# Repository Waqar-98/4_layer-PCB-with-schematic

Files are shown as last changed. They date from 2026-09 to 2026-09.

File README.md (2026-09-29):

4-Layer ESP32 Sensor Board

A battery-powered, USB-C rechargeable ESP32-C3 sensor node integrating environmental (temperature/humidity/pressure), ambient light, and sound sensing, with onboard USB-to-UART programming, microSD data logging, and an I2C display header. This repository is a **revision** of the original 2-layer design, re-laid-out as a **4-layer PCB** (dedicated inner power/ground planes) for improved signal integrity and routing.

| | |
|---|---|
| **MCU/Module** | ESP32-C3-WROOM-02-H4 (U3) |
| **USB-UART Bridge** | Silicon Labs CP2102N-A02-GQFN20 (U4) |
| **Layers** | 4 (F.Cu, In1.Cu, In2.Cu, B.Cu) |
| **Interfaces** | USB-C (USB 2.0), I2C, microSD (SPI), SPI NOR flash, GPIO breakout |
| **Power** | USB-C 5 V input, single-cell LiPo (JST 2 mm), onboard charge management |
| **Revision** | 2 (4-layer revision) |
| **Status** | In development |

---

## Table of Contents

1. [Overview](#1-overview)
2. [Features](#2-features)
3. [Hardware Description](#3-hardware-description)
4. [Schematics](#4-schematics)
5. [PCB Layout](#5-pcb-layout)
6. [ESP32-C3 Pin Mapping](#6-esp32-c3-pin-mapping)
7. [Connector Pinout](#7-connector-pinout)
8. [Power Supply](#8-power-supply)
9. [Getting Started](#9-getting-started)
10. [Repository Structure](#10-repository-structure)
11. [Bill of Materials](#11-bill-of-materials)
12. [Revision History](#12-revision-history)

---

## 1. Overview

This board is a compact, self-contained sensor node built around the ESP32-C3-WROOM-02-H4 module. It integrates a BME280 environmental sensor, a TEMT6000 ambient light sensor, and an electret microphone with an adjustable-gain amplifier, alongside a microSD card slot and an external SPI NOR flash for local data logging. Power comes from either USB-C or a single-cell LiPo battery, with onboard charge management and power-path switching so the board can run and charge simultaneously. An onboard CP2102N provides USB-to-UART programming and an automatic reset/bootloader-entry circuit, so no external programmer is required.

This revision re-lays out the board on **4 copper layers** instead of 2, adding dedicated inner power (3.3 V) and ground planes. This improves return-path continuity and reduces plane impedance/noise for the analog sensor front-ends (microphone amplifier, light sensor) and the SPI/I2C digital buses, compared with the original 2-layer version.

## 2. Features

- **ESP32-C3-WROOM-02-H4** (U3) — RISC-V single-core Wi-Fi/BLE module
- **BME280** (U7) environmental sensor — temperature, humidity, and pressure over I2C, address-select pad for 0x76/0x77
- **TEMT6000X01** (Q1) ambient light phototransistor with RC-filtered analog output
- **Electret microphone** (MK1, CMC-5042PF-AC) with a **MAX4466EXK+T** (U8) op-amp amplifier and a trimmer potentiometer (R17, 100 kΩ) for adjustable gain
- **microSD card slot** (J3, GSD090012SEU) on a shared SPI bus
- **32 Mbit external SPI NOR flash** (U6, W25Q32JVSSIQ) sharing the same SPI bus with an independent chip select, for onboard data logging separate from the module's program flash
- **Onboard USB-to-UART bridge** (U4, CP2102N-A02-GQFN20) with USB ESD protection (U5, USBLC6-2SC6) — no external FTDI/CH340 adapter needed to program the board
- **Automatic reset/bootloader-entry circuit** using two BC817 transistors (Q2, Q3) driven from DTR/RTS, following the standard ESP32 auto-program sequence
- **USB-C power input** (J1) with 5.1 kΩ CC pull-downs for default 5 V/USB 2.0 negotiation
- **LiPo charge management** via a **MCP73871** charger IC (U1) with power-path management, tri-color charge-status LEDs (charging/charged/power-good), and battery connector (J2, JST 2 mm)
- **LM1117MPX-3.3** LDO (U2) regulates the system 3.3 V rail
- Manual **BOOT** and **RESET** buttons (SW1, SW2) in addition to the automatic DTR/RTS circuit
- I2C header (J4) for an external OLED display
- 5-pin breakout header (J6) exposing 3.3 V, GND, and three spare GPIOs (GPIO8, GPIO18, GPIO19)
- Five test points (TP1–TP5) on the shared SPI bus (MOSI, MISO, SCLK, CS_SD, CS) for debugging
- **4-layer stack-up** with dedicated inner 3.3 V and GND planes (this revision)

## 3. Hardware Description

**Power input and charging.** USB-C VBUS (J1) passes through a resettable fuse (F1) to the `+5V_USB` rail. This rail feeds a MCP73871 LiPo charger IC (U1) configured with power-path management: it charges a single-cell LiPo connected at J2 while simultaneously supplying the system load from its `OUT` pin, so the board can operate while charging. Three status outputs (`STAT1`, `STAT2`, `PG`) drive a red/green/blue LED trio (D1–D3) through 470 Ω resistors, giving a visual charge/power-good indication. `OUT` feeds through a ferrite bead (FB1) into an LM1117MPX-3.3 LDO (U2), which produces the board's 3.3 V rail used by every other block.

**MCU and USB programming.** The ESP32-C3-WROOM-02-H4 (U3) is the central module. A CP2102N-A02-GQFN20 USB-to-UART bridge (U4), protected by a USBLC6-2SC6 ESD array (U5) on the USB data lines, connects the module's TX/RX to the host PC and exposes green/red (D5/D6) activity LEDs on its GPIO.2/GPIO.3 lines. DTR and RTS from the CP2102N drive two BC817 transistors (Q2, Q3) that implement the standard auto-reset/auto-bootloader circuit on the `EN` and `BOOT` (GPIO9) lines, so the board can be flashed without manually holding a button. Manual BOOT (SW1) and RESET (SW2) buttons are also provided, each with an RC debounce network.

Notably, because the ESP32-C3's boot-mode strapping pin is GPIO9 (unlike the original ESP32, which straps on GPIO0), this design routes GPIO9 to the `BOOT` net for auto-programming and frees GPIO0 for use as an analog input for the microphone signal (`MIC_OUT`).

**Storage.** A microSD socket (J3, GSD090012SEU) and a 32 Mbit SPI NOR flash (U6, W25Q32JVSSIQ) share one SPI bus (`MOSI_DI`, `MISO_DO`, `SCLK`) with independent chip-select lines (`CS_SD`, `CS`). Series resistors (R15, R20, R22 — annotated on the schematic as ~50 Ω) sit on the shared bus lines to damp ringing at high SPI clock rates. Five test points (TP1–TP5) break out the same bus for probing.

**Sensors.** A BME280 (U7) provides temperature, humidity, and pressure over I2C, with SDA/SCL pull-ups (R24, R25) and a pad to select the I2C address by tying `SDO` to GND (0x76) or `VDDIO` (0x77) — this board ties it to GND. A TEMT6000X01 phototransistor (Q1) with a 10 kΩ pull-down (R23) and RC filtering forms a simple ambient-light sensor read as an analog voltage. An electret microphone (MK1) is biased and AC-coupled into a MAX4466EXK+T op-amp (U8) configured as a non-inverting amplifier; a 22 kΩ resistor plus a 100 kΩ trimmer potentiometer (R31, R17) in the feedback path set the gain, with a 100 pF capacitor (C20) rolling off high-frequency noise.

**User interface.** A 4-pin I2C header (J4, B4B-XH-AM) breaks out 3.3 V/SDA/SCL/GND for an external OLED display. A 5-pin header (J6) exposes 3.3 V, GND, and the three GPIOs (GPIO8/18/19) not otherwise used by the design.

**Stack-up (this revision).** The board was re-laid-out from 2 to 4 copper layers: `F.Cu` (top signal), `In1.Cu` (inner plane), `In2.Cu` (inner plane), `B.Cu` (bottom signal). The inner layers are used as continuous 3.3 V and GND planes, giving the top/bottom signal layers a solid adjacent reference plane and shortening high-frequency return paths for the SPI bus and analog front-ends.

## 4. Schematics

**Power and battery management** (root sheet — USB-C input, LiPo charger, LDO regulator, power-indicator LED, battery connector)

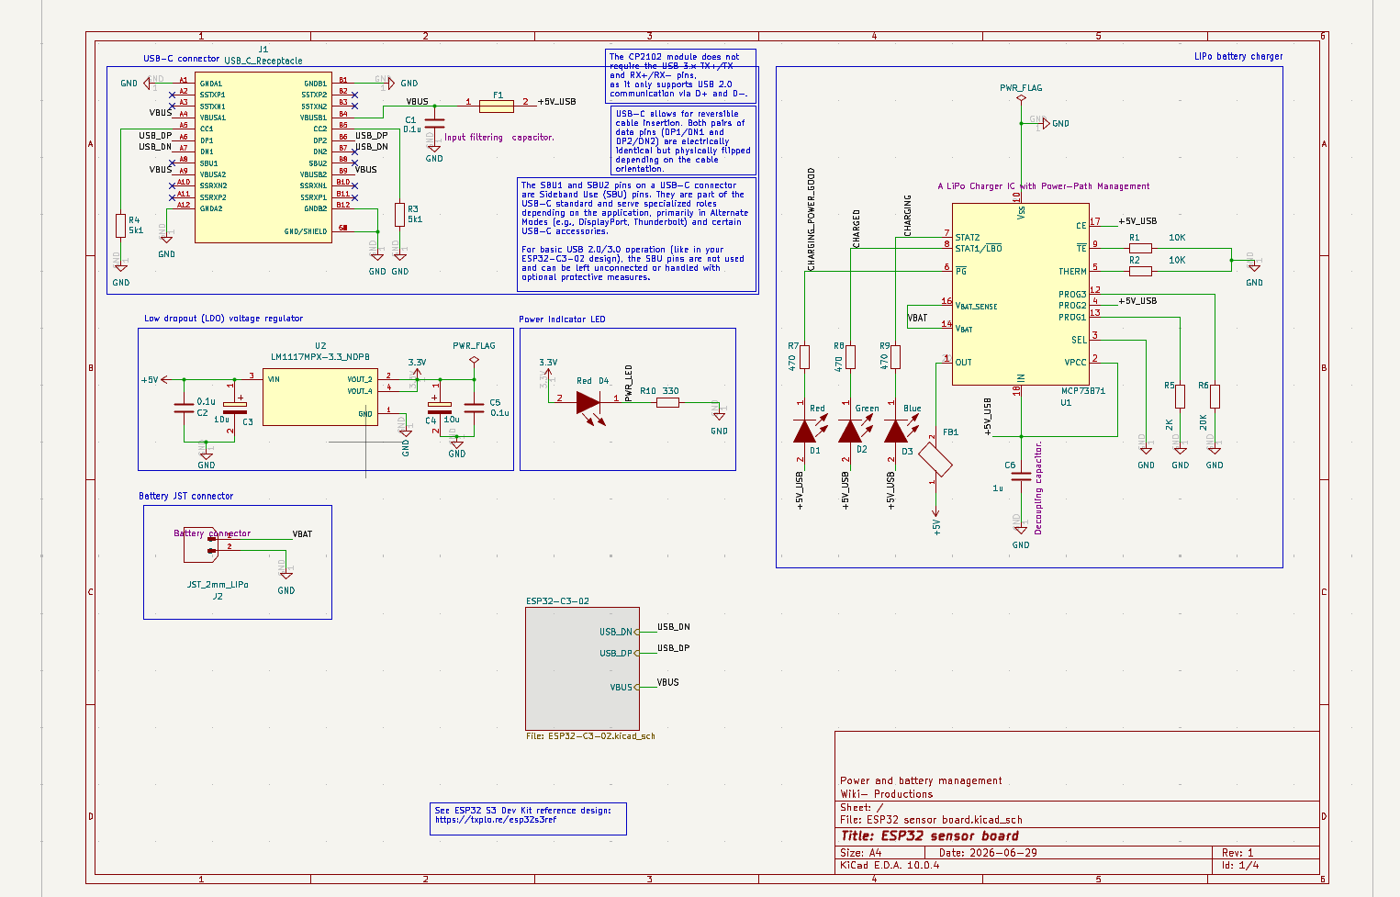
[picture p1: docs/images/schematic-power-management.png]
Power and battery management schematic


**ESP32-C3-02 and USB-to-UART converter** (MCU, CP2102N USB bridge, SPI flash, microSD module, test points)

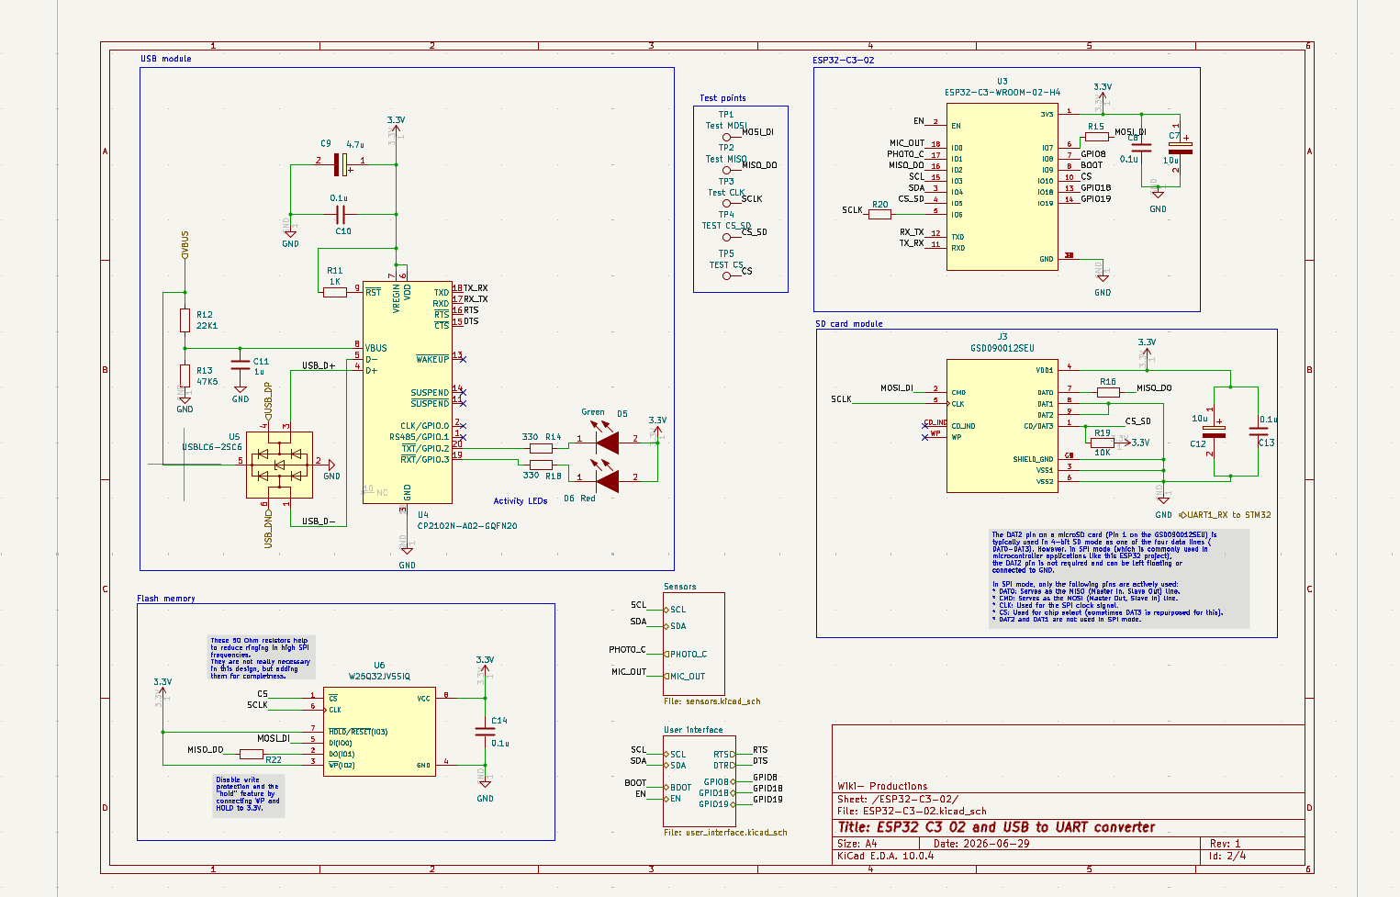
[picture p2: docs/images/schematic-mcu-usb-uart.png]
ESP32-C3-02 and USB-to-UART schematic


**Sensors** (BME280, TEMT6000 light sensor, electret microphone and amplifier)

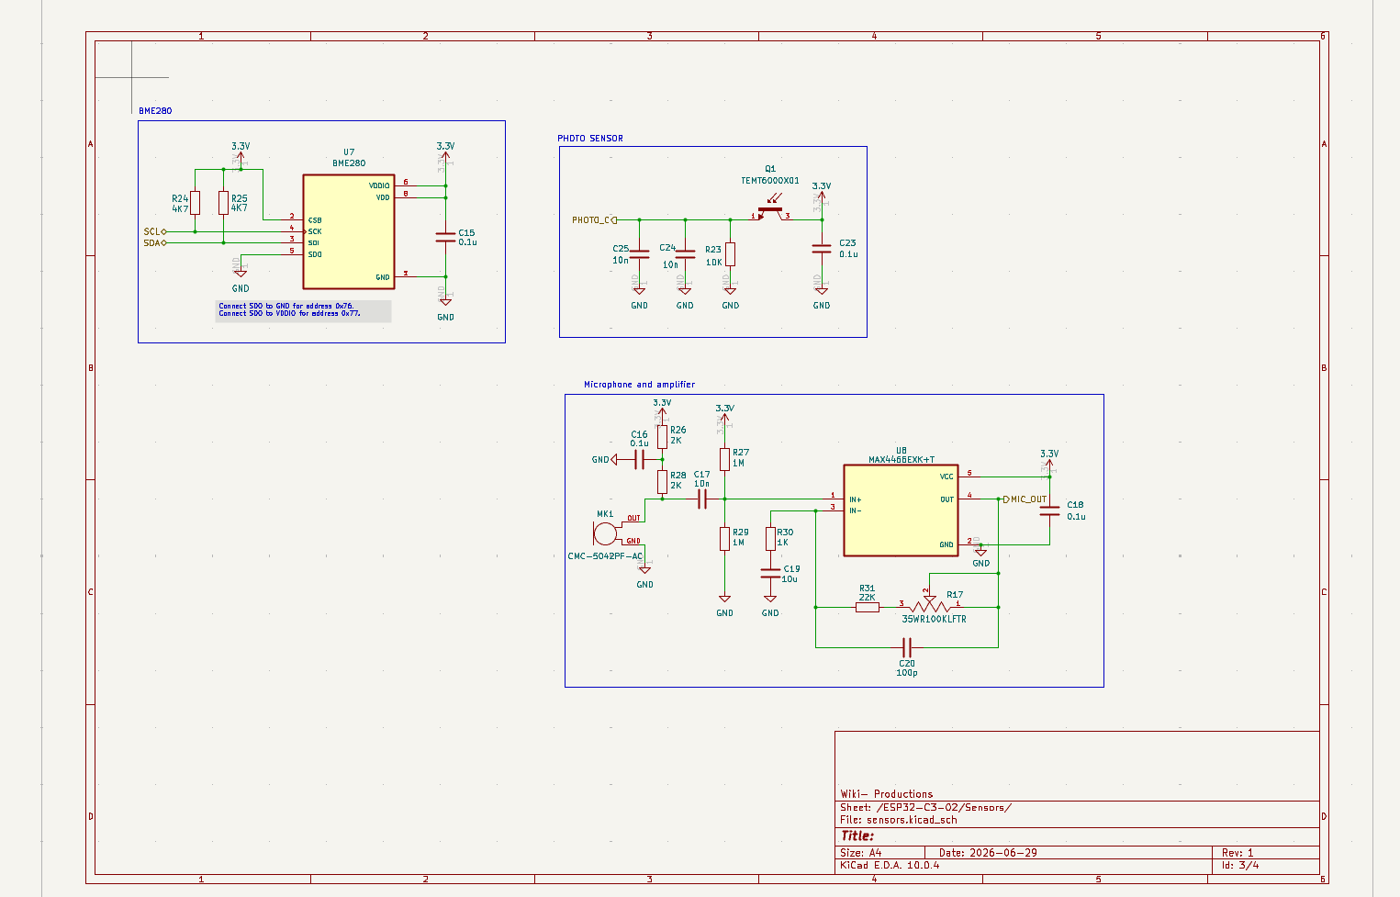
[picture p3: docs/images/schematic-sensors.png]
Sensors schematic


**User interface** (OLED I2C header, GPIO breakout header, reset/boot buttons, auto-program circuit)

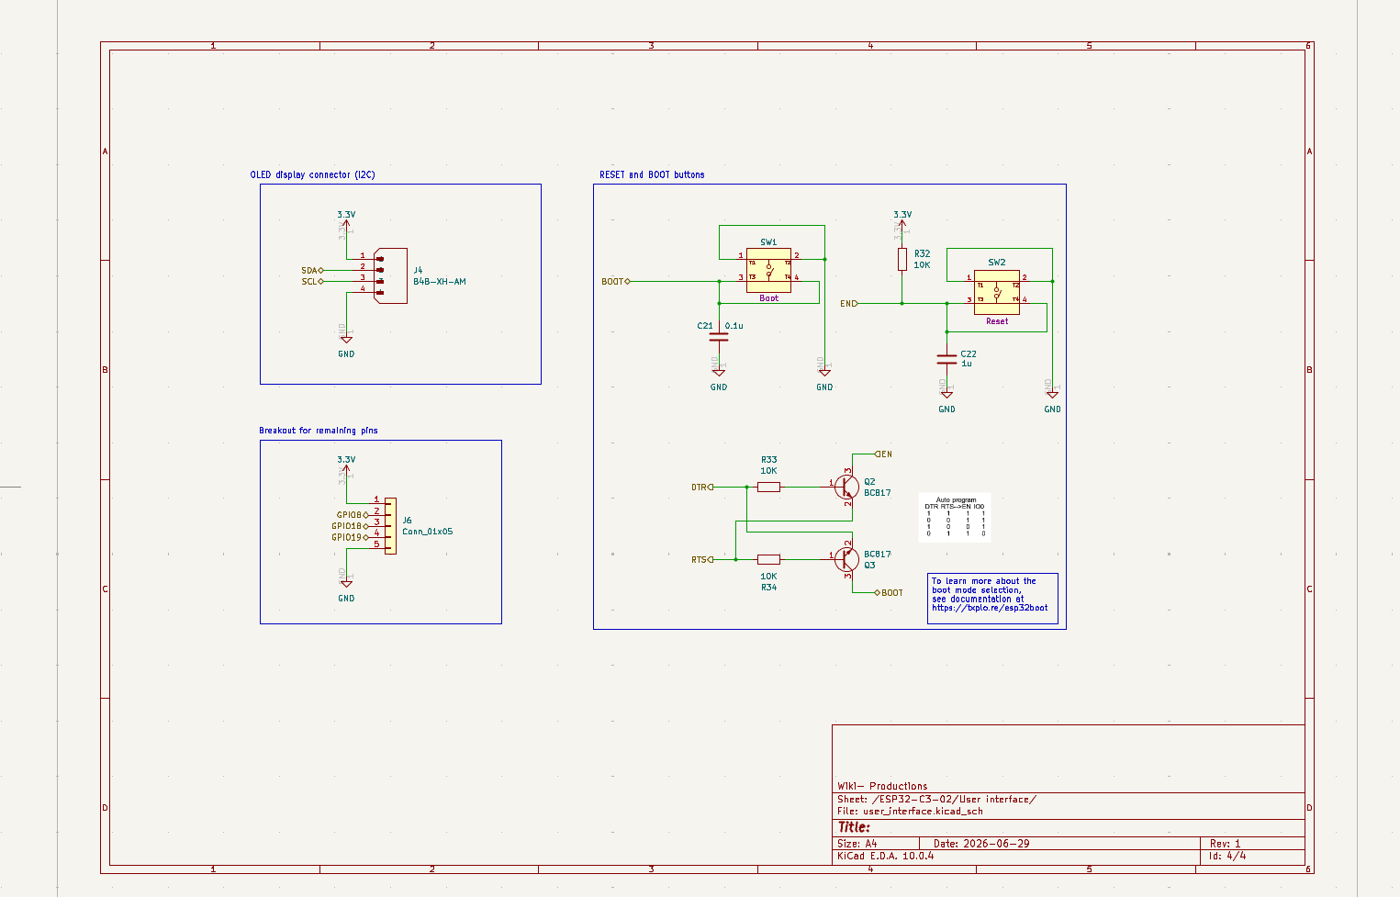
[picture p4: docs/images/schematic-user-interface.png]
User interface schematic


## 5. PCB Layout

Four-layer board (top copper in red, bottom copper in blue, inner planes not separately colored in the 2D view) with a stepped outline: the sensor cluster (microphone, light sensor, BME280) sits along the top edge, charging/regulation/USB circuitry occupies the left and lower-left, and the ESP32 module, SPI flash, and microSD slot are grouped on the right where the board extends further along the top edge. A hatched keep-out zone sits directly next to the ESP32-C3-WROOM-02 footprint, consistent with the module's onboard PCB antenna clearance requirement. A second hatched/unpopulated zone, silkscreened `proto#2`, appears to be a reserved prototyping area. The layout includes multiple mounting holes and five silkscreened test points (TP1–TP5) on the shared SPI bus — exact hole counts, diameters, and keep-out dimensions should be confirmed against the PCB source file.

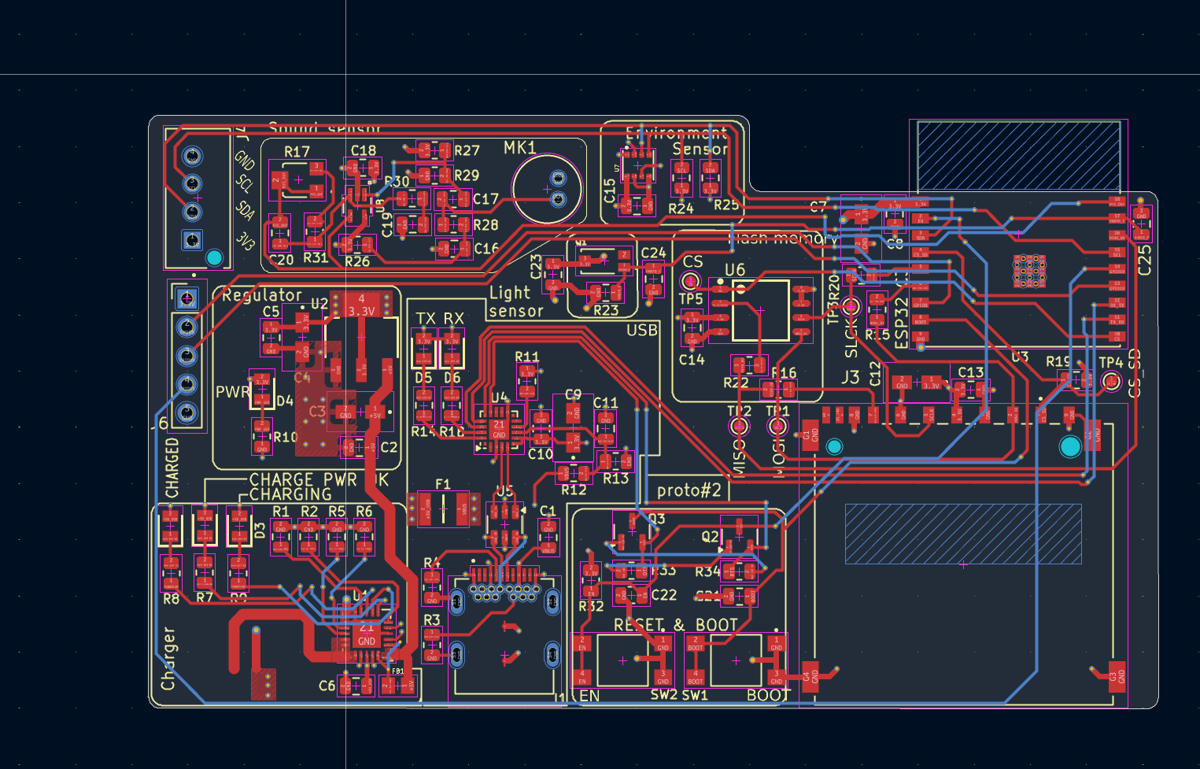
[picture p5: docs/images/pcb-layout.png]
PCB layout


**3D Render**

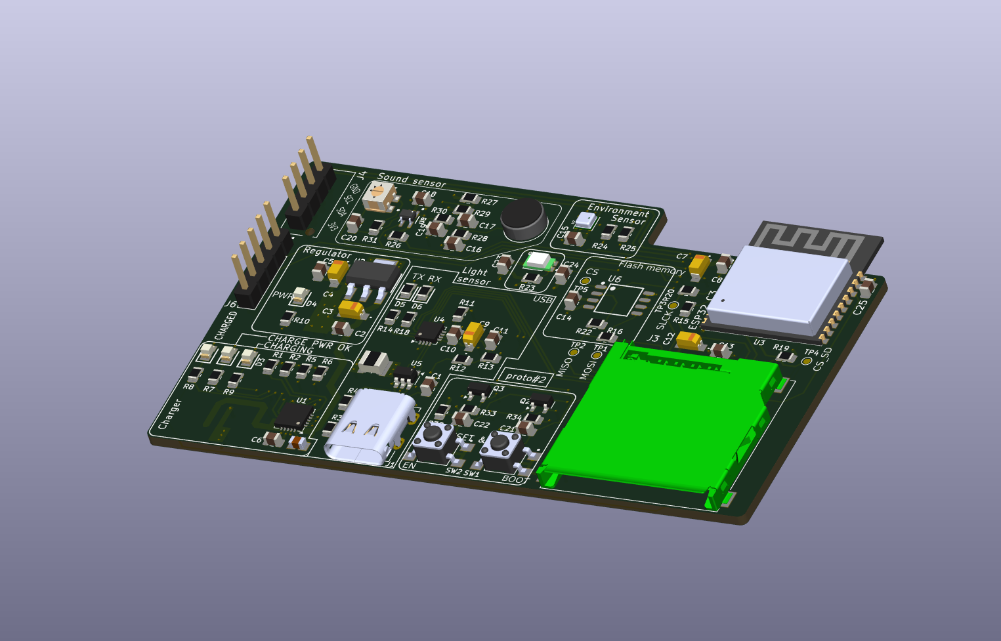
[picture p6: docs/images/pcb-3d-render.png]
PCB 3D render


## 6. ESP32-C3 Pin Mapping

Pin assignments below are read directly from the ESP32-C3-WROOM-02-H4 (U3) schematic symbol. Verify against the source design files prior to firmware development.

| Module Pin | GPIO | Net / Function |
|---|---|---|
| 1 | 3V3 | 3.3 V supply |
| 2 | EN | Chip enable / reset (auto-program + RESET button) |
| 18 | IO0 | `MIC_OUT` — microphone amplifier analog output |
| 17 | IO1 | `PHOTO_C` — light sensor analog output |
| 16 | IO2 | `MISO_DO` — shared SPI bus (flash + microSD) |
| 15 | IO3 | `SCL` — I2C clock (BME280, OLED header) |
| 3 | IO4 | `SDA` — I2C data (BME280, OLED header) |
| 4 | IO5 | `CS_SD` — microSD chip select |
| 5 | IO6 | `SCLK` — shared SPI bus clock (via R20) |
| 6 | IO7 | `MOSI_DI` — shared SPI bus data out (via R15) |
| 7 | IO8 | `GPIO8` — broken out to J6 |
| 8 | IO9 | `BOOT` — boot-mode strap / auto-program (via Q3) |
| 10 | IO10 | `CS` — SPI flash chip select |
| 13 | IO18 | `GPIO18` — broken out to J6 |
| 14 | IO19 | `GPIO19` — broken out to J6 |
| 12 | TXD | `RX_TX` — to CP2102N |
| 11 | RXD | `TX_RX` — from CP2102N |
| — | GND | Ground |

## 7. Connector Pinout

Pin assignments below are derived from the schematics. Verify against the source design files and PCB silkscreen prior to integration.

**J1 — USB-C Receptacle (USB 2.0 only)**

Standard USB-C receptacle; only the VBUS, GND, D+/D− and CC1/CC2 pins are used (SBU1/SBU2 and the SuperSpeed pairs are unconnected). CC1 and CC2 each carry a 5.1 kΩ pull-down (R4, R3) to present the board as a default-power USB 2.0 sink.

**J2 — Battery Connector (JST_2mm_LiPo)**

| Pin | Signal |
|-----|---|
| 1 | VBAT (+) |
| 2 | GND |

**J3 — microSD Socket (GSD090012SEU), SPI mode**

| Pin | Signal |
|-----|---|
| 4 | VDD1 (3.3 V) |
| 2 | CMD ← `MOSI_DI` |
| 5 | CLK ← `SCLK` |
| 7 | DAT0 → `MISO_DO` (pull-up R16) |
| 8 | DAT1 (not used in SPI mode) |
| 9 | DAT2 |
| 1 | CD/DAT3 → `CS_SD` (pull-up R19, 10 kΩ) |
| — | CD_IND, WP (not populated) |
| 3, 6 | VSS1/VSS2 (GND) |
| GS | SHIELD_GND |

**J4 — OLED Display Connector, I2C (B4B-XH-AM, 4-pin)**

| Pin | Signal |
|-----|---|
| 1 | 3.3 V |
| 2 | SDA |
| 3 | SCL |
| 4 | GND |

**J6 — Spare GPIO Breakout (Conn_01x05, 5-pin)**

| Pin | Signal |
|-----|---|
| 1 | 3.3 V |
| 2 | GPIO8 |
| 3 | GPIO18 |
| 4 | GPIO19 |
| 5 | GND |

**TP1–TP5 — Test Points**

| Test Point | Net |
|---|---|
| TP1 | MOSI_DI |
| TP2 | MISO_DO |
| TP3 | SCLK |
| TP4 | CS_SD |
| TP5 | CS |

## 8. Power Supply

| Parameter | Value |
|---|---|
| Input | USB-C 5 V (VBUS, via resettable fuse F1) or single-cell LiPo (J2) |
| Charger IC | MCP73871 (U1) — LiPo charger with power-path management |
| Regulator | LM1117MPX-3.3/NDPB (U2), LDO |
| System rail | 3.3 V |
| Charge status indication | Tri-color LED (D1 red / D2 green / D3 blue) driven from STAT2, STAT1/LBO, PG |
| Power-good indicator | Red LED (D4) on the 3.3 V rail via R10 (330 Ω) |
| Input filtering | C1 (0.1 µF) on VBUS; C2/C3 (0.1 µF/10 µF) on LDO input; C4/C5 (10 µF/0.1 µF) on LDO output; C6 (1 µF) on charger IN |

## 9. Getting Started

1. **Power:** Connect a USB-C cable to J1 for bench power/programming, and/or connect a single-cell LiPo battery to J2 for portable operation. The board can run while charging.
2. **Programming:** Connect the board to a host PC via USB-C. The onboard CP2102N enumerates as a serial port; the DTR/RTS auto-program circuit puts the ESP32-C3 into bootloader mode automatically when flashing (e.g. via `esptool.py` or the Arduino/PlatformIO/ESP-IDF toolchains). Use the BOOT (SW1) and RESET (SW2) buttons manually if auto-programming is disabled or unresponsive.
3. **Serial/communication:** The BME280 and any OLED display connected at J4 share the I2C bus on GPIO3 (SCL) / GPIO4 (SDA). The microSD card and external SPI flash share one SPI bus (GPIO6/7/2) with independent chip selects on GPIO5 (`CS_SD`) and GPIO10 (`CS`).
4. **Opening the design:** Open `hardware/kicad/ESP32 sensor board.kicad_pro` in KiCad 8/9+ to view or edit the schematic and 4-layer PCB layout.
5. **Fabrication:** Fabrication-ready Gerbers and drill files for the current 4-layer revision are in `hardware/gerbers/`, generated directly from the KiCad PCB source.

## 10. Repository Structure

```
.
├── docs/
│   └── images/
│       ├── schematic-power-management.png
│       ├── schematic-mcu-usb-uart.png
│       ├── schematic-sensors.png
│       ├── schematic-user-interface.png
│       ├── pcb-layout.png
│       └── pcb-3d-render.png
├── hardware/
│   ├── kicad/            # Full KiCad 4-layer project source (schematics, PCB, libraries, datasheets)
│   ├── gerbers/           # Fabrication-ready Gerber and drill files (4-layer)
│   └── bom.csv            # Bill of materials, exported from the schematic
└── README.md
```

## 11. Bill of Materials

A full bill of materials, generated from the schematic, is available at [`hardware/bom.csv`](hardware/bom.csv). Key components:

| Reference | Component | Description |
|---|---|---|
| U1 | MCP73871 | LiPo charger IC with power-path management |
| U2 | LM1117MPX-3.3/NDPB | 3.3 V LDO regulator |
| U3 | ESP32-C3-WROOM-02-H4 | Wi-Fi/BLE MCU module |
| U4 | CP2102N-A02-GQFN20 | USB-to-UART bridge |
| U5 | USBLC6-2SC6 | USB D+/D− ESD protection array |
| U6 | W25Q32JVSSIQ | 32 Mbit SPI NOR flash |
| U7 | BME280 | Environmental sensor (temperature/humidity/pressure) |
| U8 | MAX4466EXK+T | Microphone amplifier op-amp |
| Q1 | TEMT6000X01 | Ambient light phototransistor |
| Q2, Q3 | BC817 | NPN transistors, auto-reset/bootloader circuit |
| MK1 | CMC-5042PF-AC | Electret microphone |
| J1 | USB_C_Receptacle | USB-C connector |
| J2 | JST_2mm_LiPo | Battery connector |
| J3 | GSD090012SEU | microSD card socket |
| J4 | B4B-XH-AM | 4-pin JST-XH, OLED I2C connector |
| J6 | Conn_01x05 | 5-pin GPIO breakout header |
| SW1, SW2 | Tactile switch | BOOT and RESET buttons |
| D1–D3 | LED (RGB, discrete) | Charge status indicator |
| D4 | LED (red) | Power-good indicator |
| D5, D6 | LED (green/red) | USB activity indicators |
| F1 | Resettable fuse | VBUS overcurrent protection |
| FB1 | Ferrite bead | Charger output filtering |

## 12. Revision History

| Revision | Date | Notes |
|---|---|---|
| 1 | 2026-06-29 | Initial 2-layer design |
| 2 | 2026-09-09 | Revised to 4-layer stack-up with dedicated inner power/ground planes; gerbers and BOM regenerated for the new layout |

---

**Author:** Waqar-98

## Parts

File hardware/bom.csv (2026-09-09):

Refs | Value | Footprint | Qty | DNP
C1 | 0.1u | Capacitor_SMD:C_0805_2012Metric | 1
C2 | 0.1u | Capacitor_SMD:C_0805_2012Metric | 1
C3 | 10u | Footprints:T491A | 1
C4 | 10u | Footprints:T491A | 1
C5 | 0.1u | Capacitor_SMD:C_0805_2012Metric | 1
C6 | 1u | Capacitor_SMD:C_0805_2012Metric | 1
C7 | 10u | Footprints:T491A | 1
C8 | 0.1u | Capacitor_SMD:C_0805_2012Metric | 1
C9 | 4.7u | Footprints:T491A | 1
C10 | 0.1u | Capacitor_SMD:C_0805_2012Metric | 1
C11 | 1u | Capacitor_SMD:C_0805_2012Metric | 1
C12 | 10u | Footprints:T491A | 1
C13 | 0.1u | Capacitor_SMD:C_0805_2012Metric | 1
C14 | 0.1u | Capacitor_SMD:C_0805_2012Metric | 1
C15 | 0.1u | Capacitor_SMD:C_0805_2012Metric | 1
C16 | 0.1u | Capacitor_SMD:C_0805_2012Metric | 1
C17 | 10n | Capacitor_SMD:C_0805_2012Metric | 1
C18 | 0.1u | Capacitor_SMD:C_0805_2012Metric | 1
C19 | 10u | Capacitor_SMD:C_0805_2012Metric | 1
C20 | 100p | Capacitor_SMD:C_0805_2012Metric | 1
C21 | 0.1u | Capacitor_SMD:C_0805_2012Metric | 1
C22 | 1u | Capacitor_SMD:C_0805_2012Metric | 1
C23 | 0.1u | Capacitor_SMD:C_0805_2012Metric | 1
C24 | 10n | Capacitor_SMD:C_0805_2012Metric | 1
C25 | 10n | Capacitor_SMD:C_0805_2012Metric | 1
D1 | Red | Footprints:LEDC2012X120N | 1
D2 | Green | Footprints:LEDC2012X120N | 1
D3 | Blue | Footprints:LEDC2012X120N | 1
D4 | Red | Footprints:LEDC2012X120N | 1
D5 | Green | Footprints:LEDC2012X120N | 1
D6 | Red | Footprints:LEDC2012X120N | 1
F1 | 0ZCH0110AF2E | Footprints:FUSC3226X100N | 1
FB1 | FBMJ2125HM330-T | Footprints:BEADC2012X105N | 1
J1 | USB_C_Receptacle | Footprints:BELFUSE_SS-52400-002 | 1
J2 | JST_2mm_LiPo | Footprints:JST_B2B-PH-SM4-TB | 1
J3 | GSD090012SEU | Footprints:AMPHENOL_GSD090012SEU | 1
J4 | B4B-XH-AM | Footprints:JST_B4B-XH-AM__LF__SN_ | 1
J6 | Conn_01x05 | Connector_PinHeader_2.54mm:PinHeader_1x05_P2.54mm_Vertical | 1
MK1 | CMC-5042PF-AC | Footprints:CUI_CMC-5042PF-AC | 1
Q1 | TEMT6000X01 | Footprints:TRANS_TEMT6000X01 | 1
Q2 | BC817 | Package_TO_SOT_SMD:SOT-23 | 1
Q3 | BC817 | Package_TO_SOT_SMD:SOT-23 | 1
R1 | 10K | Resistor_SMD:R_0805_2012Metric | 1
R2 | 10K | Resistor_SMD:R_0805_2012Metric | 1
R3 | 5k1 | Resistor_SMD:R_0805_2012Metric | 1
R4 | 5k1 | Resistor_SMD:R_0805_2012Metric | 1
R5 | 2K | Resistor_SMD:R_0805_2012Metric | 1
R6 | 20K | Resistor_SMD:R_0805_2012Metric | 1
R7 | 470 | Resistor_SMD:R_0805_2012Metric | 1
R8 | 470 | Resistor_SMD:R_0805_2012Metric | 1
R9 | 470 | Resistor_SMD:R_0805_2012Metric | 1
R10 | 330 | Resistor_SMD:R_0805_2012Metric | 1
R11 | 1K | Resistor_SMD:R_0805_2012Metric | 1
R12 | 22K1 | Resistor_SMD:R_0805_2012Metric | 1
R13 | 47K5 | Resistor_SMD:R_0805_2012Metric | 1
R14 | 330 | Resistor_SMD:R_0805_2012Metric | 1
R15 | 50 | Resistor_SMD:R_0805_2012Metric | 1
R16 | 50 | Resistor_SMD:R_0805_2012Metric | 1
R17 | 35WR100KLFTR | Footprints:TRIM_35WR100KLFTR | 1
R18 | 330 | Resistor_SMD:R_0805_2012Metric | 1
R19 | 10K | Resistor_SMD:R_0805_2012Metric | 1
R20 | 50 | Resistor_SMD:R_0805_2012Metric | 1
R22 | 50 | Resistor_SMD:R_0805_2012Metric | 1
R23 | 10K | Resistor_SMD:R_0805_2012Metric | 1
R24 | 4K7 | Resistor_SMD:R_0805_2012Metric | 1
R25 | 4K7 | Resistor_SMD:R_0805_2012Metric | 1
R26 | 2K | Resistor_SMD:R_0805_2012Metric | 1
R27 | 1M | Resistor_SMD:R_0805_2012Metric | 1
R28 | 2K | Resistor_SMD:R_0805_2012Metric | 1
R29 | 1M | Resistor_SMD:R_0805_2012Metric | 1
R30 | 1K | Resistor_SMD:R_0805_2012Metric | 1
R31 | 22K | Resistor_SMD:R_0805_2012Metric | 1
R32 | 10K | Resistor_SMD:R_0805_2012Metric | 1
R33 | 10K | Resistor_SMD:R_0805_2012Metric | 1
R34 | 10K | Resistor_SMD:R_0805_2012Metric | 1
SW1 | 1101NE | USLPT2819DT2TR:SW_USLPT2819DT2TR | 1
SW2 | 1101NE | USLPT2819DT2TR:SW_USLPT2819DT2TR | 1
TP1 | Test MOSI | TestPoint:TestPoint_Pad_D1.0mm | 1
TP2 | Test MISO | TestPoint:TestPoint_Pad_D1.0mm | 1
TP3 | Test CLK | TestPoint:TestPoint_Pad_D1.0mm | 1
TP4 | TEST CS_SD | TestPoint:TestPoint_Pad_D1.0mm | 1
TP5 | TEST CS | TestPoint:TestPoint_Pad_D1.0mm | 1
U1 | MCP73871 | Package_DFN_QFN:QFN-20-1EP_4x4mm_P0.5mm_EP2.5x2.5mm | 1
U2 | LM1117MPX-3.3_NOPB | Footprints:VREG_LM1117MPX-3.3 | 1
U3 | ESP32-C3-WROOM-02-H4 | Footprints:MODULE_ESP32-C3-WROOM-02-H4 | 1
U4 | CP2102N-A02-GQFN20 | Package_DFN_QFN:SiliconLabs_QFN-20-1EP_3x3mm_P0.5mm_EP1.8x1.8mm | 1
U5 | USBLC6-2SC6 | Package_TO_SOT_SMD:SOT-23-6 | 1
U6 | W25Q32JVSSIQ | Footprints:SOIC127P790X216-8N | 1
U7 | BME280 | Footprints:PSON65P250X250X100-8N | 1
U8 | MAX4466EXK+T | Footprints:SOT65P210X110-5N | 1

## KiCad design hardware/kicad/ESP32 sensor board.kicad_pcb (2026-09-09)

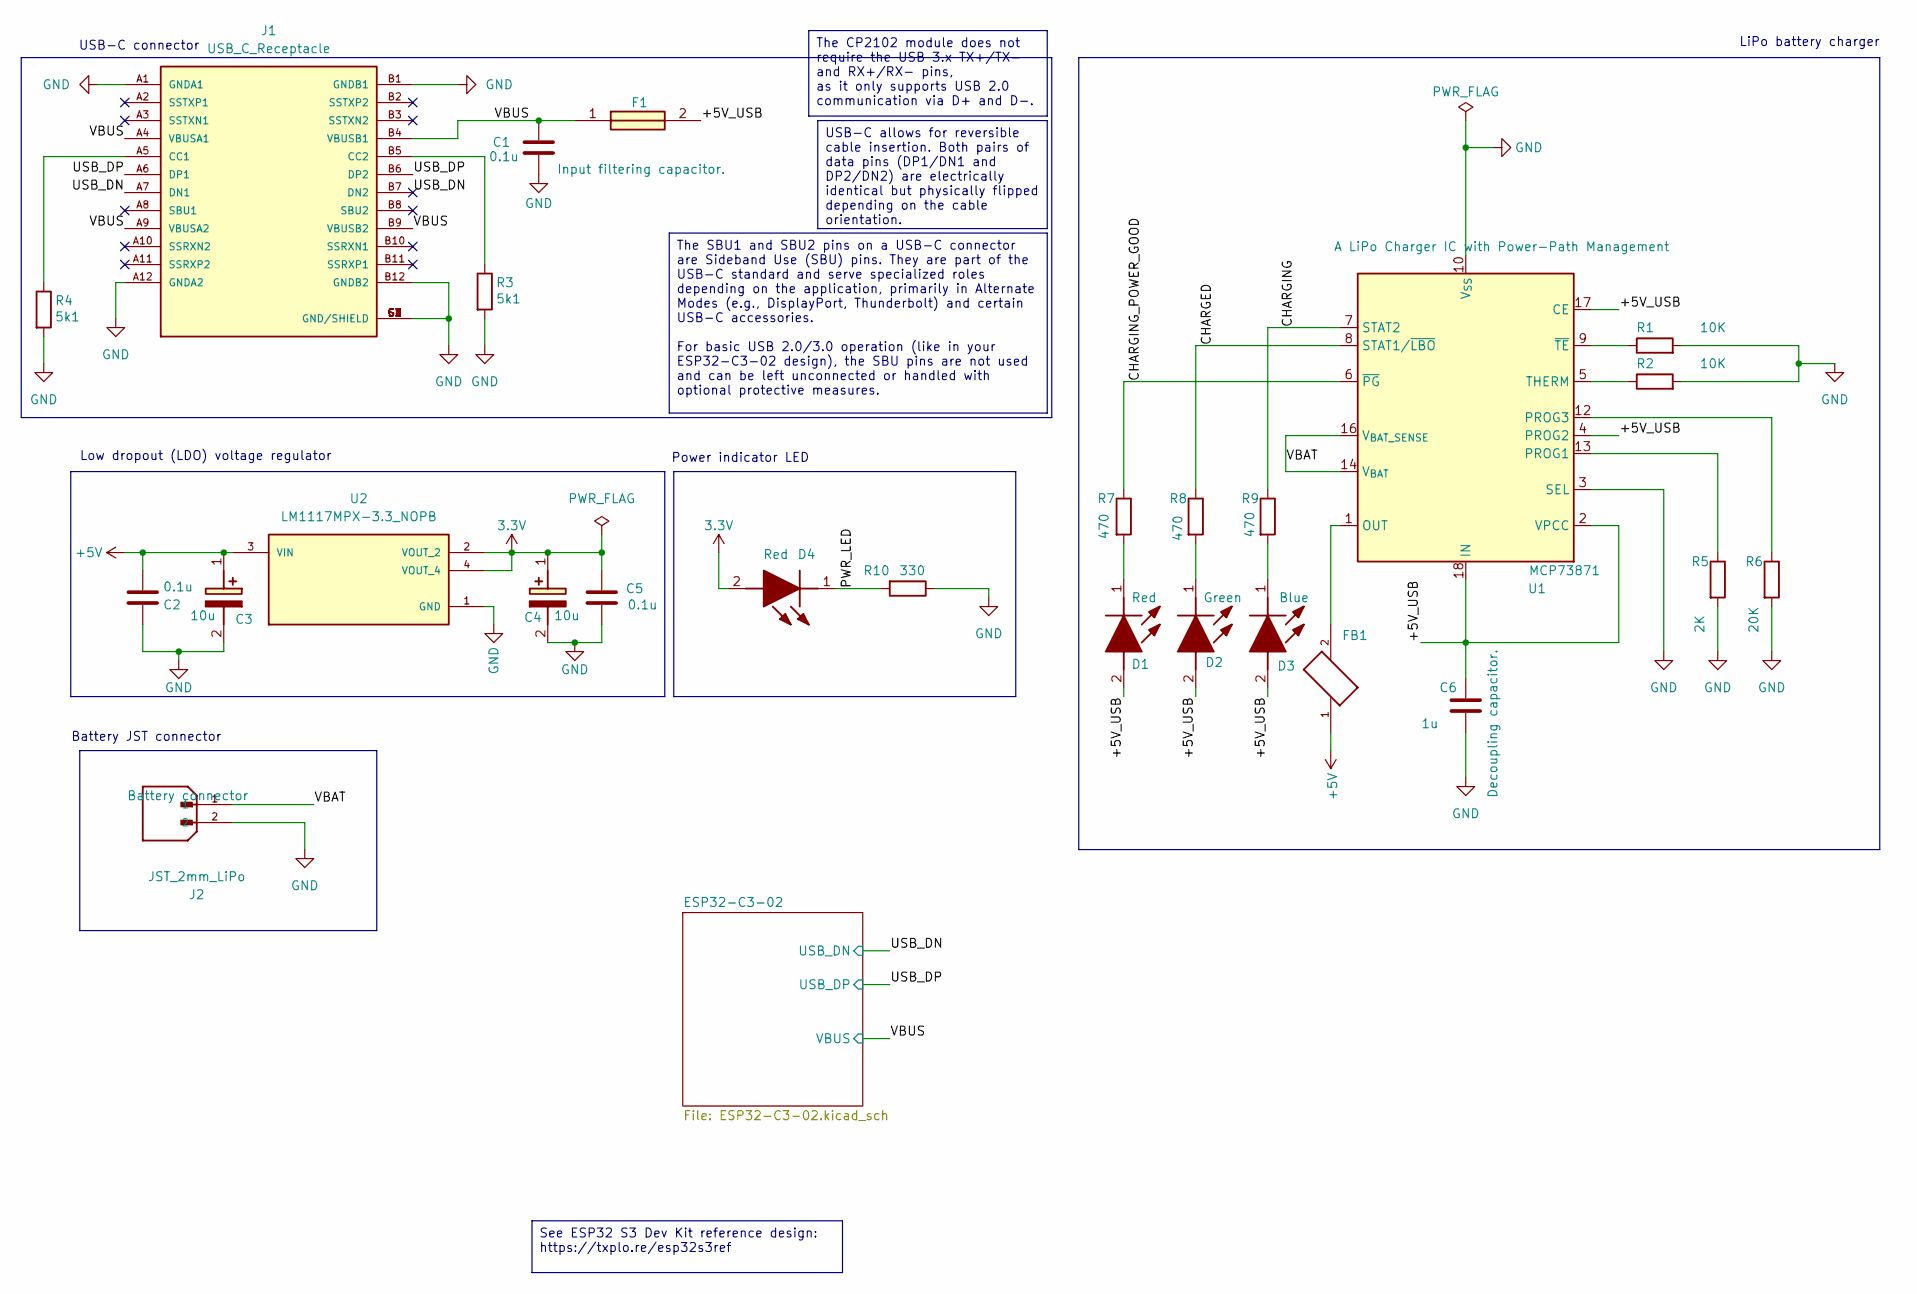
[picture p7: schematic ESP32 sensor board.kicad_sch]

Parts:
C1, C2, C5: 0.1u; C_0805_2012Metric; Voltage 1kV; Tolerance 100%
C3, C4: 10u; T491A; Voltage 1kV; Tolerance 100%; Manufacturer_Part_Number T491A106K010AT7280; Mouser Part Number 80-T491A106K107280
C6: 1u; C_0805_2012Metric; Voltage 1kV; Tolerance 100%
D1, D4: Red; LEDC2012X120N; Manufacturer_Part_Number LTST-C170KRKT; Mouser Part Number 859-LTST-C170KRKT
D2: Green; LEDC2012X120N; Manufacturer_Part_Number LTST-C170GKT; Mouser Part Number 859-LTST-C170GKT
D3: Blue; LEDC2012X120N; Manufacturer_Part_Number LTST-C170TBKT; Mouser Part Number 859-LTST-C170TBKT
F1: 0ZCH0110AF2E; FUSC3226X100N; Manufacturer_Part_Number 0ZCH0110AF2E
FB1: FBMJ2125HM330-T; BEADC2012X105N
J1: USB_C_Receptacle; BELFUSE_SS-52400-002; PARTREV A0
J2: JST_2mm_LiPo; JST_B2B-PH-SM4-TB; Manufacturer_Part_Number ?
R1, R2: 10K; R_0805_2012Metric
R3, R4: 5k1; R_0805_2012Metric
R5: 2K; R_0805_2012Metric
R6: 20K; R_0805_2012Metric
R7, R8, R9: 470; R_0805_2012Metric
R10: 330; R_0805_2012Metric
U1: MCP73871; QFN-20-1EP_4x4mm_P0.5mm_EP2.5x2.5mm; Manufacturer_Part_Number MCP73871-4CCI/ML
U2: LM1117MPX-3.3_NOPB; VREG_LM1117MPX-3.3; Mouser Part Number 926-LM1117MPX3.3NOPB

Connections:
3.3V: C4.1 (+), C5.1, D4.2 (A), U2.2 (VOUT_2), U2.4 (VOUT_4); also elsewhere on the board
+5V: C2.1, C3.1 (+), FB1.1, U2.3 (VIN)
/+5V_USB: C6.1, D1.2 (A), D2.2 (A), D3.2 (A), F1.2, U1.2 (VPCC), U1.4 (PROG2), U1.17 (CE), U1.18 (IN), U1.19 (IN)
/CHARGED: R8.1, U1.8 (STAT1/~LBO)
/CHARGING: R9.1, U1.7 (STAT2)
/CHARGING_POWER_GOOD: R7.1, U1.6 (~PG)
/PWR_LED: D4.1 (K), R10.2
/USB_DN: J1.A7 (DN1), J1.B7 (DN2); also elsewhere on the board
/USB_DP: J1.A6 (DP1), J1.B6 (DP2); also elsewhere on the board
/VBAT: J2.1, U1.14 (V_{BAT}), U1.15 (V_{BAT}), U1.16 (V_{BAT_SENSE})
/VBUS: C1.1, F1.1, J1.A4 (VBUSA1), J1.A9 (VBUSA2), J1.B4 (VBUSB1), J1.B9 (VBUSB2); also elsewhere on the board
unnamed: D1.1 (K), R7.2
unnamed: D2.1 (K), R8.2
unnamed: D3.1 (K), R9.2
unnamed: FB1.2, U1.1 (OUT), U1.20 (OUT)
unnamed: J1.A5 (CC1), R4.1
unnamed: J1.B5 (CC2), R3.1
unnamed: R5.1, U1.13 (PROG1)
unnamed: R6.1, U1.12 (PROG3)
unnamed: R2.1, U1.5 (THERM)
unnamed: R1.1, U1.9 (~TE)

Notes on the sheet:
USB-C connector
LiPo battery charger
Power indicator LED
Low dropout (LDO) voltage regulator
Battery JST connector
The CP2102 module does not require the USB 3.x TX+/TX- and RX+/RX- pins, as it only supports USB 2.0 communication via D+ and D-.
See ESP32 S3 Dev Kit reference design: https://txplo.re/esp32s3ref
The SBU1 and SBU2 pins on a USB-C connector are Sideband Use (SBU) pins. They are part of the USB-C standard and serve specialized roles depending on the application, primarily in Alternate Modes (e.g., DisplayPort, Thunderbolt) and certain USB-C accessories. For basic USB 2.0/3.0 operation (like i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
USB-C allows for reversible cable insertion. Both pairs of data pins (DP1/DN1 and DP2/DN2) are electrically identical but physically flipped depending on the cable orientation.

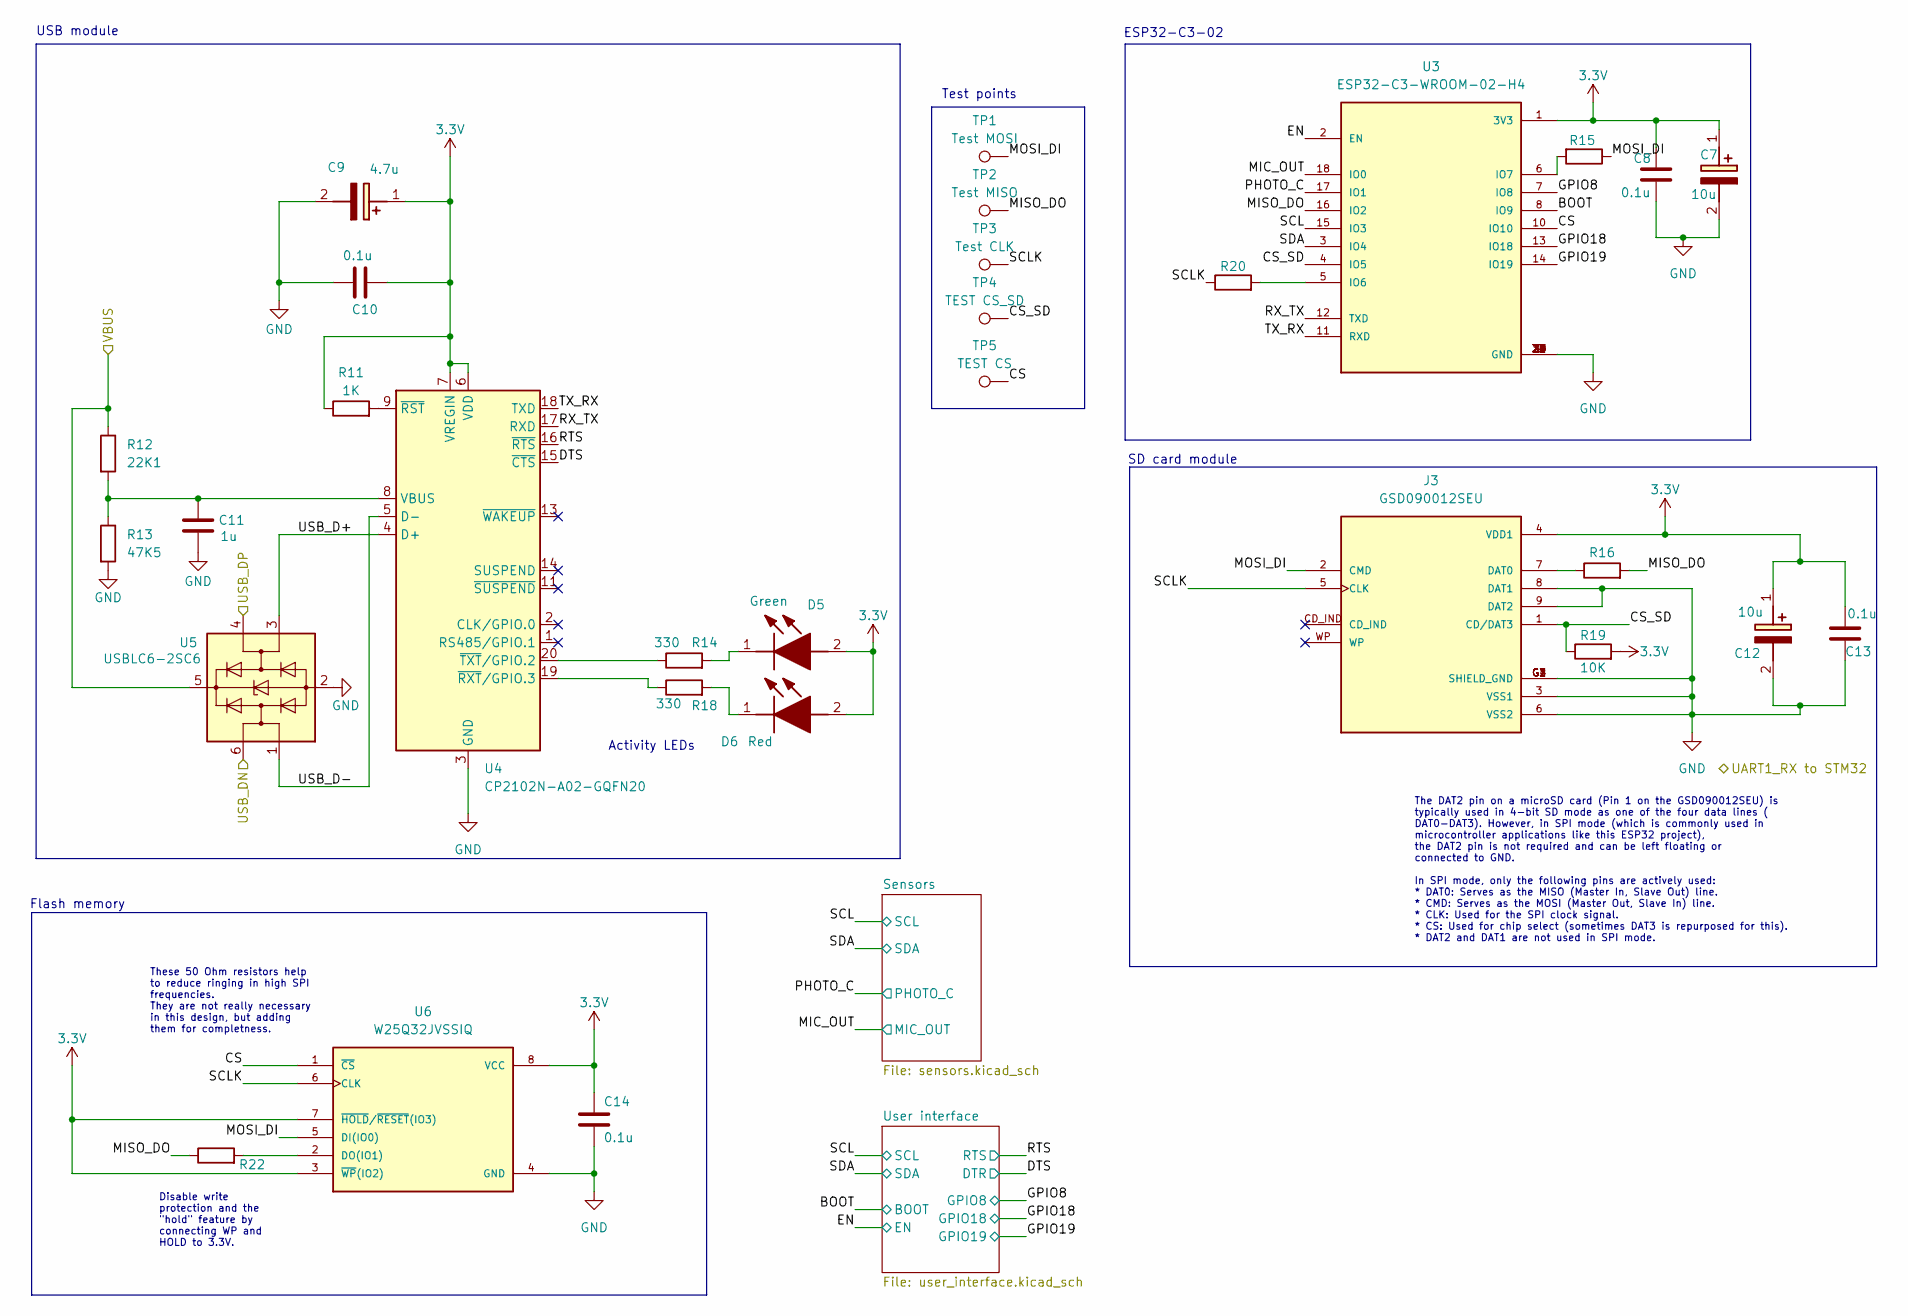
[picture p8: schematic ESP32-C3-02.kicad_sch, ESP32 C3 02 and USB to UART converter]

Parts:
C7, C12: 10u; T491A; Voltage 1kV; Tolerance 100%; Manufacturer_Part_Number T491A106K010AT7280; Mouser Part Number 80-T491A106K107280
C8, C10, C13, C14: 0.1u; C_0805_2012Metric; Voltage 1kV; Tolerance 100%
C9: 4.7u; T491A; Voltage 1kV; Tolerance 100%; Manufacturer_Part_Number T491A106K010AT7280; Mouser Part Number 80-T491A106K107280
C11: 1u; C_0805_2012Metric; Voltage 1kV; Tolerance 100%
D5: Green; LEDC2012X120N; Manufacturer_Part_Number LTST-C170GKT; Mouser Part Number 859-LTST-C170GKT
D6: Red; LEDC2012X120N; Manufacturer_Part_Number LTST-C170KRKT; Mouser Part Number 859-LTST-C170KRKT
J3: GSD090012SEU; AMPHENOL_GSD090012SEU; PARTREV E
R11: 1K; R_0805_2012Metric
R12: 22K1; R_0805_2012Metric
R13: 47K5; R_0805_2012Metric
R14, R18: 330; R_0805_2012Metric
R15, R16, R20, R22: 50; R_0805_2012Metric
R19: 10K; R_0805_2012Metric
TP1: Test MOSI; TestPoint_Pad_D1.0mm
TP2: Test MISO; TestPoint_Pad_D1.0mm
TP3: Test CLK; TestPoint_Pad_D1.0mm
TP4: TEST CS_SD; TestPoint_Pad_D1.0mm
TP5: TEST CS; TestPoint_Pad_D1.0mm
U3: ESP32-C3-WROOM-02-H4; MODULE_ESP32-C3-WROOM-02-H4; Manufacturer_Part_Number ESP32-C3-WROOM-02-H4
U4: CP2102N-A02-GQFN20; SiliconLabs_QFN-20-1EP_3x3mm_P0.5mm_EP1.8x1.8mm; Manufacturer_Part_Number CP2102N-A02-GQFN20
U5: USBLC6-2SC6; SOT-23-6; Manufacturer_Part_Number USBLC6-2SC6; Mouser Part Number 511-USBLC6-2SC6
U6: W25Q32JVSSIQ; SOIC127P790X216-8N; M_PART_NUMBER W25QXX

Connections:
3.3V: C7.1 (+), C8.1, C9.1 (+), C10.1, C12.1 (+), C13.2, C14.1, D5.2 (A), D6.2 (A), J3.4 (VDD1), R11.1, R19.2, U3.1 (3V3), U4.6 (VDD), U4.7 (VREGIN), U6.3 (~WP(IO2)), U6.7 (~HOLD/~RESET(IO3)), U6.8 (VCC); also elsewhere on the board
/ESP32-C3-02/CS: TP5.1, U3.10 (IO10), U6.1 (~CS)
/ESP32-C3-02/CS_SD: J3.1 (CD/DAT3), R19.1, TP4.1, U3.4 (IO5)
/ESP32-C3-02/DTS: U4.15 (~CTS); also elsewhere on the board
/ESP32-C3-02/GPIO8: U3.7 (IO8); also elsewhere on the board
/ESP32-C3-02/GPIO18: U3.13 (IO18); also elsewhere on the board
/ESP32-C3-02/GPIO19: U3.14 (IO19); also elsewhere on the board
/ESP32-C3-02/MIC_OUT: U3.18 (IO0); also elsewhere on the board
/ESP32-C3-02/MISO_DO: R16.2, R22.1, TP2.1, U3.16 (IO2)
/ESP32-C3-02/MOSI_DI: J3.2 (CMD), R15.1, TP1.1, U6.5 (DI(IO0))
/ESP32-C3-02/PHOTO_C: U3.17 (IO1); also elsewhere on the board
/ESP32-C3-02/RTS: U4.16 (~RTS); also elsewhere on the board
/ESP32-C3-02/RX_TX: U3.12 (TXD), U4.17 (RXD)
/ESP32-C3-02/SCL: U3.15 (IO3); also elsewhere on the board
/ESP32-C3-02/SCLK: J3.5 (CLK), R20.1, TP3.1, U6.6 (CLK)
/ESP32-C3-02/SDA: U3.3 (IO4); also elsewhere on the board
/ESP32-C3-02/TX_RX: U3.11 (RXD), U4.18 (TXD)
/ESP32-C3-02/USB_D+: U4.4 (D+), U5.3 (I/O2)
/ESP32-C3-02/USB_D-: U4.5 (D-), U5.1 (I/O1)
/USB_DN: U5.6 (I/O1); also elsewhere on the board
/USB_DP: U5.4 (I/O2); also elsewhere on the board
/VBUS: R12.1, U5.5 (VBUS); also elsewhere on the board
unnamed: D5.1 (K), R14.2
unnamed: D6.1 (K), R18.2
unnamed: J3.7 (DAT0), R16.1
unnamed: R20.2, U3.5 (IO6)
unnamed: R15.2, U3.6 (IO7)
unnamed: C11.1, R12.2, R13.1, U4.8 (VBUS)
unnamed: R11.2, U4.9 (~RST)
unnamed: R18.1, U4.19 (~RXT/GPIO.3)
unnamed: R14.1, U4.20 (~TXT/GPIO.2)
unnamed: R22.2, U6.2 (DO(IO1))

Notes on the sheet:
SD card module
Activity LEDs
Flash memory
USB module
Test points
ESP32-C3-02
Disable write protection and the "hold" feature by connecting WP and HOLD to 3.3V.
The DAT2 pin on a microSD card (Pin 1 on the GSD090012SEU) is typically used in 4-bit SD mode as one of the four data lines ( DAT0-DAT3). However, in SPI mode (which is commonly used in microcontroller applications like this ESP32 project), the DAT2 pin is not required and can be left floating or c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
These 50 Ohm resistors help to reduce ringing in high SPI frequencies. They are not really necessary in this design, but adding them for completness.

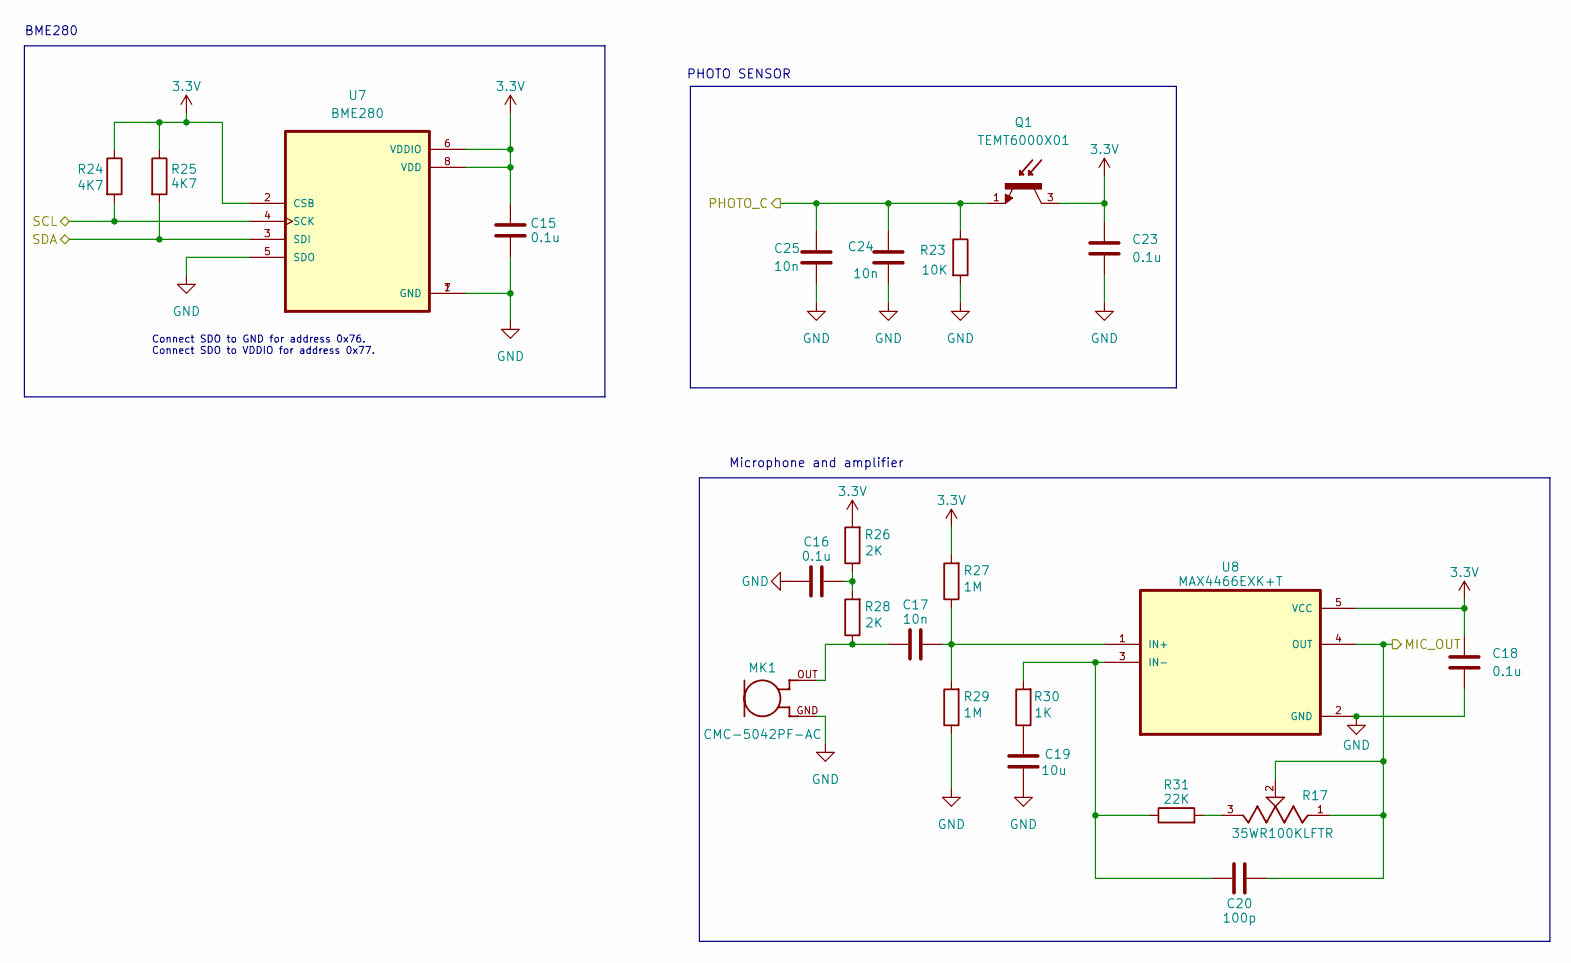
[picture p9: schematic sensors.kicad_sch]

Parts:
C15: 0.1u; C_0805_2012Metric; Voltage 1kV; Tolerance 100%
C16, C18, C23: 0.1u; C_0805_2012Metric
C17, C24, C25: 10n; C_0805_2012Metric
C19: 10u; C_0805_2012Metric
C20: 100p; C_0805_2012Metric
MK1: CMC-5042PF-AC; CUI_CMC-5042PF-AC; Manufacturer_Part_Number CMC-5042PF-AC
Q1: TEMT6000X01; TRANS_TEMT6000X01; PARTREV 1.9
R17: 35WR100KLFTR; TRIM_35WR100KLFTR; PARTREV D
R23: 10K; R_0805_2012Metric
R24, R25: 4K7; R_0805_2012Metric
R26, R28: 2K; R_0805_2012Metric
R27, R29: 1M; R_0805_2012Metric
R30: 1K; R_0805_2012Metric
R31: 22K; R_0805_2012Metric
U7: BME280; PSON65P250X250X100-8N; Manufacturer_Part_Number BME280
U8: MAX4466EXK+T; SOT65P210X110-5N; Manufacturer_Part_Number MAX4466EXK+T

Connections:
3.3V: C15.2, C18.1, C23.1, Q1.3, R24.1, R25.1, R26.2, R27.2, U7.2 (CSB), U7.6 (VDDIO), U7.8 (VDD), U8.5 (VCC); also elsewhere on the board
/ESP32-C3-02/MIC_OUT: C20.2, R17.1, R17.2, U8.4 (OUT); also elsewhere on the board
/ESP32-C3-02/PHOTO_C: C24.1, C25.1, Q1.1, R23.1; also elsewhere on the board
/ESP32-C3-02/SCL: R24.2, U7.4 (SCK); also elsewhere on the board
/ESP32-C3-02/SDA: R25.2, U7.3 (SDI); also elsewhere on the board
unnamed: C16.1, R26.1, R28.2
unnamed: C17.2, MK1.OUT, R28.1
unnamed: C19.2, R30.1
unnamed: R17.3, R31.2
unnamed: C17.1, R27.1, R29.2, U8.1 (IN+)
unnamed: C20.1, R30.2, R31.1, U8.3 (IN-)

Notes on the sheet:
PHOTO SENSOR
Microphone and amplifier
BME280
Connect SDO to GND for address 0x76. Connect SDO to VDDIO for address 0x77.

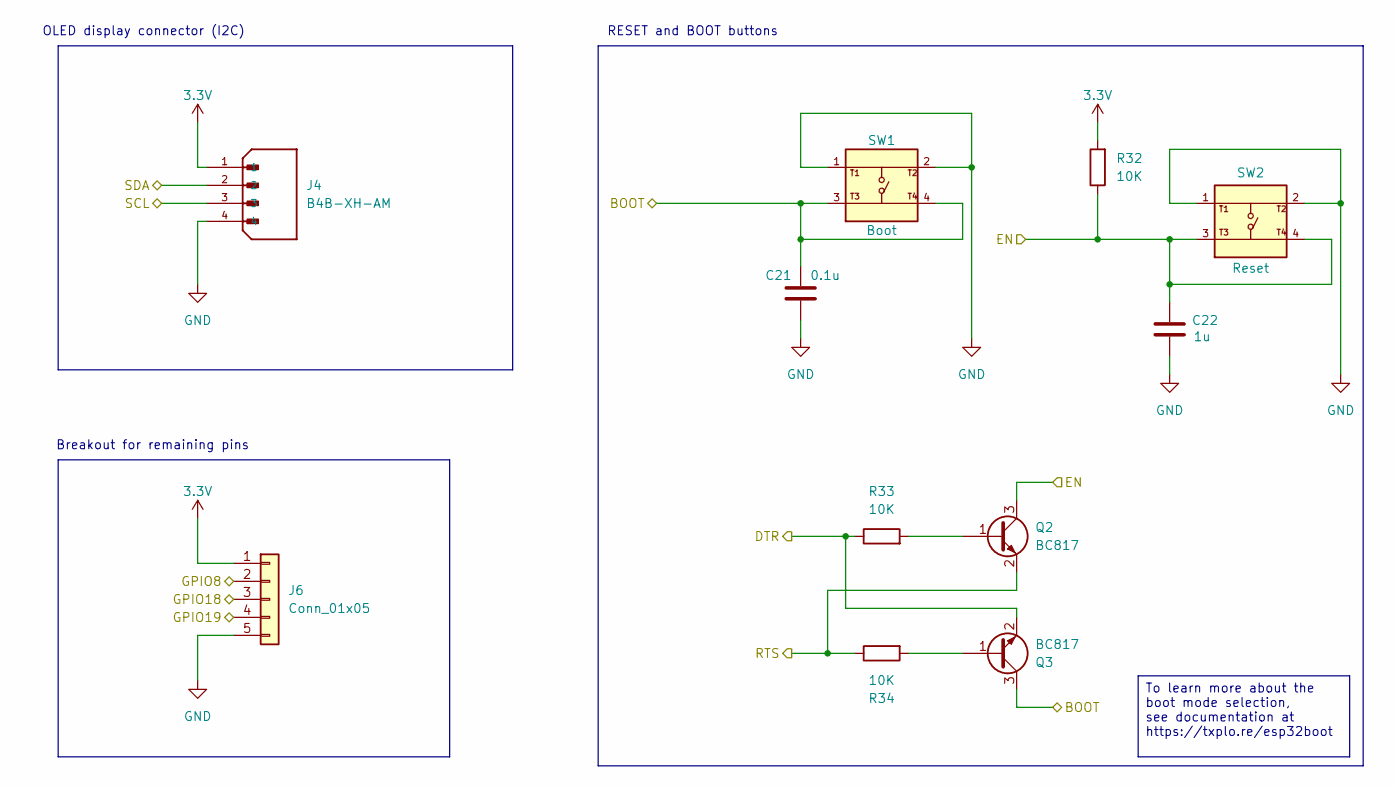
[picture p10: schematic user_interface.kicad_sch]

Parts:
C21: 0.1u; C_0805_2012Metric; Voltage 1kV; Tolerance 100%
C22: 1u; C_0805_2012Metric; Voltage 1kV; Tolerance 100%
J4: B4B-XH-AM; JST_B4B-XH-AM__LF__SN_; PARTREV N/A
J6: Conn_01x05; PinHeader_1x05_P2.54mm_Vertical
Q2, Q3: BC817; SOT-23; Manufacturer_Part_Number BC817
R32, R33, R34: 10K; R_0805_2012Metric
SW1, SW2: 1101NE; SW_USLPT2819DT2TR; Mfg Part# 8-004 SMD Button 8x3.6mm Height=2.5mm

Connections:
3.3V: J4.1, J6.1, R32.2; also elsewhere on the board
/ESP32-C3-02/DTS: Q3.2 (E), R33.1; also elsewhere on the board
/ESP32-C3-02/GPIO8: J6.2; also elsewhere on the board
/ESP32-C3-02/GPIO18: J6.3; also elsewhere on the board
/ESP32-C3-02/GPIO19: J6.4; also elsewhere on the board
/ESP32-C3-02/RTS: Q2.2 (E), R34.1; also elsewhere on the board
/ESP32-C3-02/SCL: J4.3; also elsewhere on the board
/ESP32-C3-02/SDA: J4.2; also elsewhere on the board
unnamed: Q2.1 (B), R33.2
unnamed: Q3.1 (B), R34.2

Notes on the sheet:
OLED display connector (I2C)
RESET and BOOT buttons
Breakout for remaining pins
To learn more about the boot mode selection, see documentation at https://txplo.re/esp32boot

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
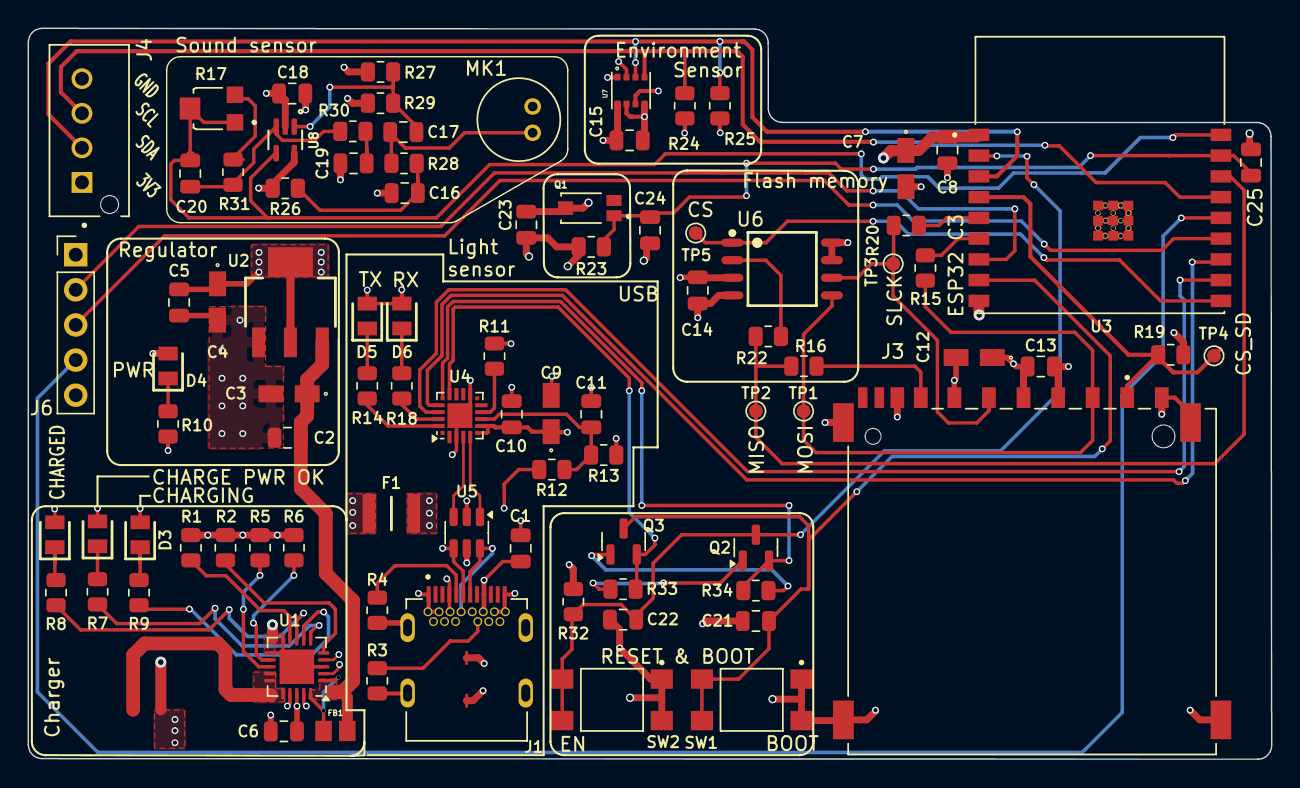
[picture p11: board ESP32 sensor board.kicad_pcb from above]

Board: 4 copper layers, 89.9 x 52.8 mm, 89 parts (0 on the bottom side), 60 nets.

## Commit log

2026-09-09 Initial upload: 4-layer ESP32 sensor board revision
    KiCad project source, schematic/PCB renders, fabrication-ready
    4-layer gerbers, and BOM.
    [ESP32 sensor board-B_Cu.gbl, ESP32 sensor board-B_Mask.gbs, ESP32 sensor board-B_Paste.gbp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]
2026-09-29 4-Layer ESP32 Sensor Board
    Updated project title in README to reflect 4-layer design.
